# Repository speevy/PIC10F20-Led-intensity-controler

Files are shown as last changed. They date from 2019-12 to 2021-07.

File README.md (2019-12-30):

# Led intensity controler for IKEA JANSJÖ using PIC 10F200

This project is for improving the IKEA JANSJÖ led light with power control. Includes both software and hardware design.

I have build myself the circuit using a prototyping board of 15 x 4 tenths of an inch, that fits inside the original lamp switch.

I have also designed a 2 layer pcb board for smd components with micro-usb port for programming the pic. (Not tested yet, boards are on the way)

It consist of two push-buttons, one for increasing power, and another for decreasing. Pressing the two buttons at the same time switches on and off the ligth.

The design can be adapted for use in other similar applications. Be aware on the voltage and current of the device.

**WARNING!** There are two kinds of power suppliers for LED lamps: Voltage sources and current sources. This design is *ONLY* meant for the Voltage sources.

_UPDATE_: Having seen the teardown of the device in this video: https://www.youtube.com/watch?v=H4aymFmak9Y I realized that although this circuit is powered by a voltage source, is later converted to current source to drive the LED.

Having seen the comments on the video, seems that the main point of failure of the lamp are the switches (already fixed that ;)) and the power supply. There also seem that the driver chips are able to work at 5V, so the design could be rebuild to power the lamp from uUSB connector, using standard USB power supplies.

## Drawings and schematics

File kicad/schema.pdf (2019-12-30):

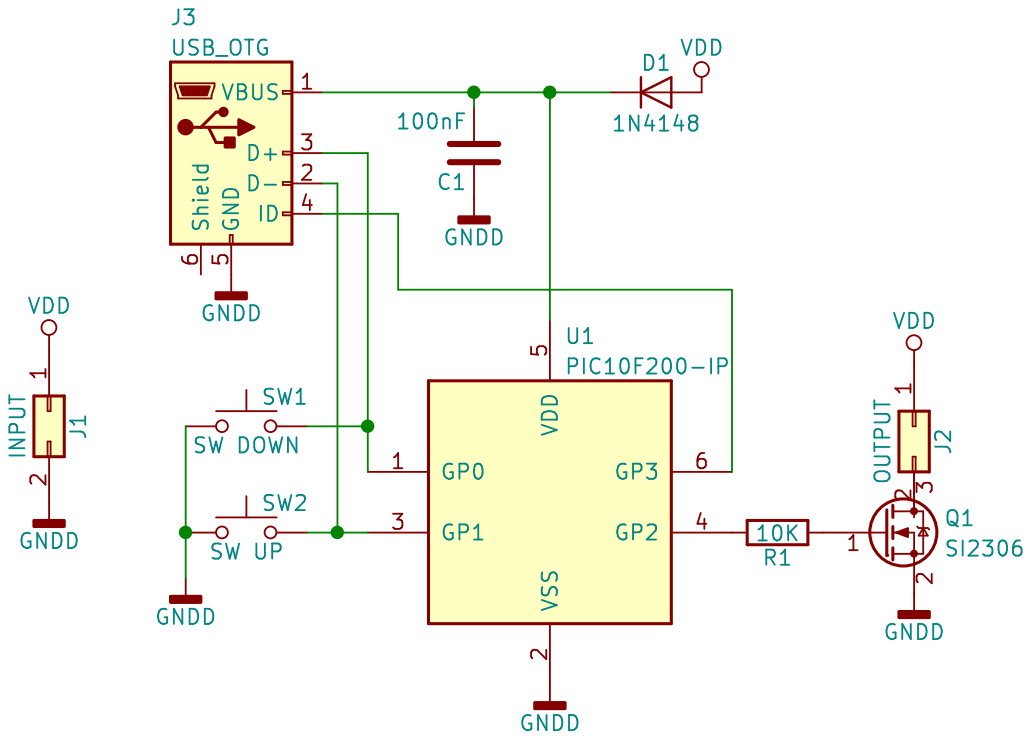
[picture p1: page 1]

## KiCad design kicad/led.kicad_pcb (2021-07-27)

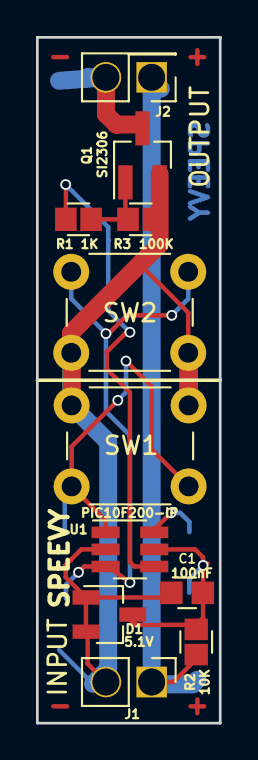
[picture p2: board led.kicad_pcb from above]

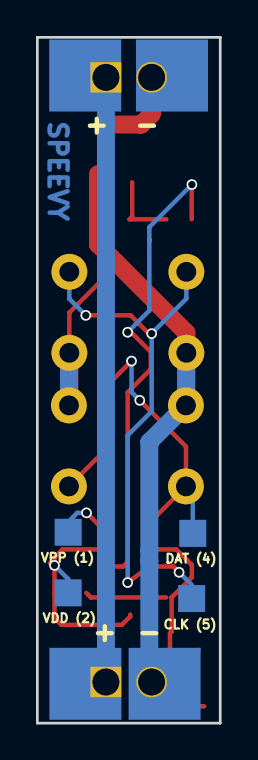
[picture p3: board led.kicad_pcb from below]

Board: 2 copper layers, 10.2 x 38.1 mm, 15 parts (4 on the bottom side), 9 nets.

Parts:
C1: 100nF; C_0805
D1: 5.1V; D_SOT-23_ANK
J1: INPUT; Pin_Header_Straight_1x02_Pitch2.54mm
J2: OUTPUT; Pin_Header_Straight_2x01_Pitch2.54mm
J3: VDD (2); Measurement_Point_Square-SMD-Pad_Small
J4: VPP (1); Measurement_Point_Square-SMD-Pad_Small
J5: DAT (4); Measurement_Point_Square-SMD-Pad_Small
J6: CLK (5); Measurement_Point_Square-SMD-Pad_Small
Q1: SI2306; SOT-23_Handsoldering
R1: 1K; R_0805
R2: 10K; R_0805
R3: 100K; R_0805
SW1: SW DOWN; SW_PUSH_6mm_h7.3mm
SW2: SW UP; SW_PUSH_6mm_h7.3mm
U1: PIC10F200-IP; SOT-23-6_Handsoldering

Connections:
GNDD: C1.1, D1.2, J1.2, Q1.2, R3.1, SW1.1, SW2.1, U1.2
unnamed: C1.2, D1.1, J3.1, R2.2, U1.5
unnamed: J2.2, Q1.3
unnamed: J4.1, U1.6
unnamed: J5.1, SW1.2, U1.1
unnamed: J6.1, SW2.2, U1.3
unnamed: Q1.1, R1.1, R3.2
unnamed: R1.2, U1.4
VDD: J1.1, J2.1, R2.1

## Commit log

2018-03-25 Refactor + improve button detection
2018-03-25 Schematic + PCB WiP
    [led.kicad_pcb, led.sch]
2018-03-30 Schematic + PCB SMD WiP
    [led.kicad_pcb, led_smd.kicad_pcb, led_smd.sch]
2018-04-07 Schematic + PCB SMD new version
    [led.sch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]
2018-04-07 New version of the algorithm: - less steps and lesss power for first step - pushing both buttons powers on(near full power)/off. - power off pushing both buttons is now the same state as going to pow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
2018-04-21 Refactor of the duty cicle algorithm (now first value is minimum, and value 0 is power off). Added comments.
2019-12-30 Added a diode to isolate "power" VDD to microcontroler VDD. Changed some footprints to enable bigger resistor and capacitor. Moved a bit the headers in order to fit. Added extra soldering pads to VIN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
    [led-B.Cu.gbr, led-B.Mask.gbr, led-B.SilkS.gbr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]
2021-07-27 Modified to allow input voltages > 5V. Also removed micro usb connector for programming, and added some test points in its place.
    [led.kicad_pcb, led.sch]
